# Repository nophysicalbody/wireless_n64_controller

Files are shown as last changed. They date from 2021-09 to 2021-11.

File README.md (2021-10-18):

# Wireless Nintendo 64 Controller Project

## Overview

This page describes my project to make a Nintendo 64 controller wireless. 
You plug your favourite controller into the transmitter, then plug the receiver into the console.
There is currently no support for controller peripherals (e.g.: memory cards, rumble packs).

The system is built on Arduino/AVR and utilises the popular RFM69 radio modules for wireless communication.

## Hardware

### Transmitter

The transmitter (what you plug the controller into) consists of:

* 3.3V Arduino Pro Mini, the brains of the operation
* Sparkfun RFM69 Breakout, to enable wireless communication
* Breadboard, breadboard power supply and a power source (for portability, I used a 7.4V battery)
* Half a N64 controller extension cord (the end that connects to a controller)
* A 1K ohm resistor to pull the N64 signal line high.

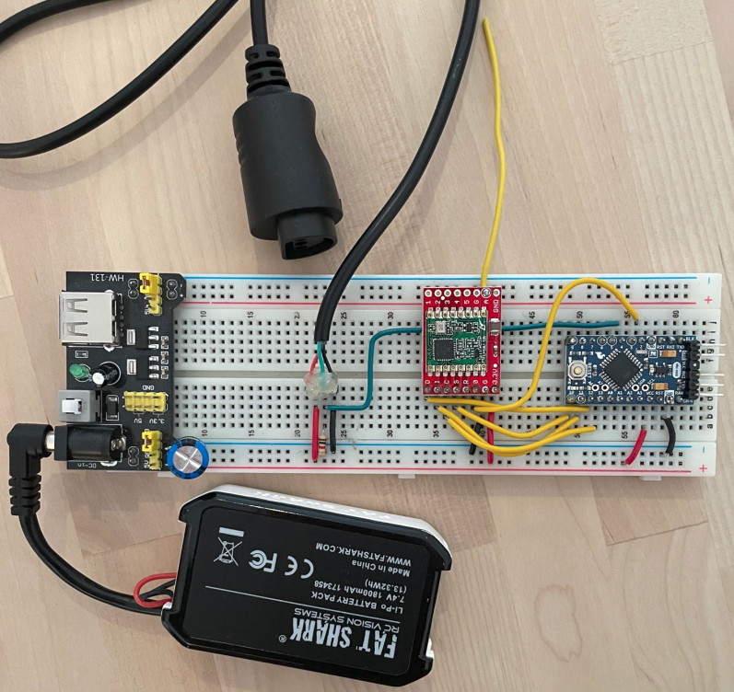
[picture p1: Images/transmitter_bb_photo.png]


### Receiver

The receiver (what you plug into the console) consists of:

* Another 3.3V Arduino Pro Mini
* Another Sparkfun RFM69 Breakout
* ATtiny85 dedicated to handling communication with the console
* Breadboard - no need for breadboard power supply as this board sources power from the console
* The other half of the N64 controller extension cord (the end that connects to the console)
* [Optional] - A bi-color LED indicator & resistor (this lights up when a button is pressed)

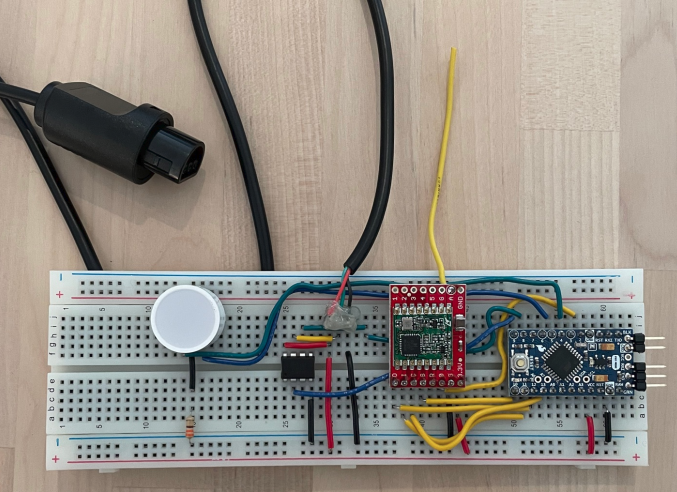
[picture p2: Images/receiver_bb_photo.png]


## Software

Transmitter software is located in the **wireless_n64_controller** sketch.
Flash **wireless_n64_controller.ino** to the Arduino Pro Mini on the transmitter.

Receiver software is located in the **wireless_n64_receiver** sketch.
Flash **wireless_n64_receiver.ino** to the Arduino Pro Mini on the receiver.
Flash **ATtiny85-n64-controller.ino** to the ATtiny85 on the receiver - refer to the "ATtiny85 programming instructions" document.

## Breadboard prototype set up

### Transmitter (Connect to controller)

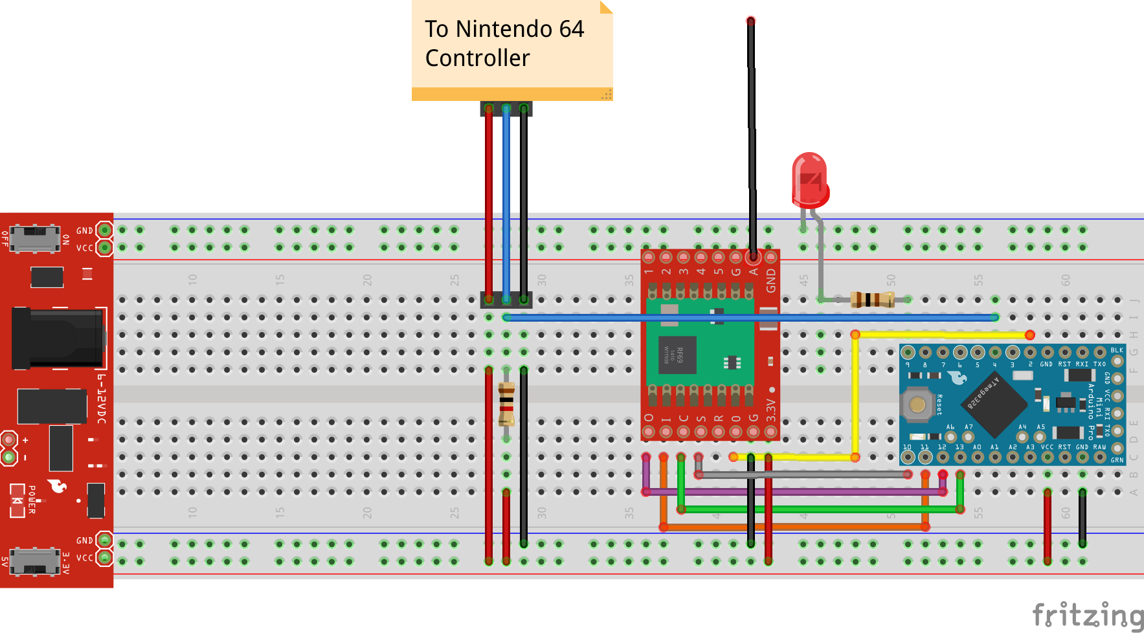
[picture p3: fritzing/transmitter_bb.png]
Transmitter


### Receiver (Connect to console)

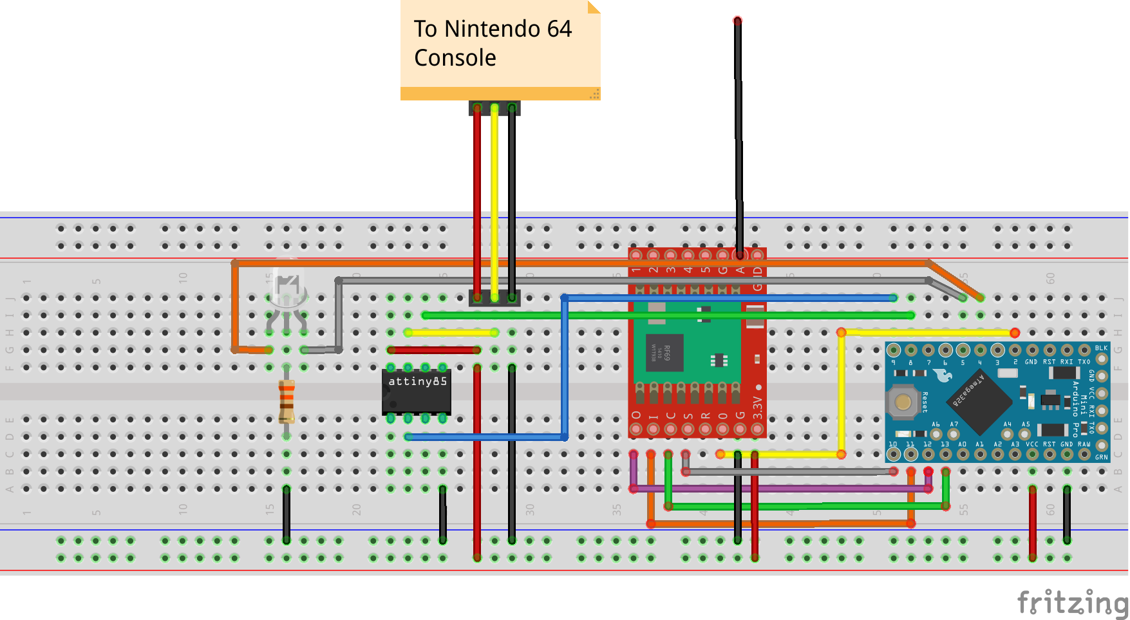
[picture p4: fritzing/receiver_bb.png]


#### ATtiny85 pinout:

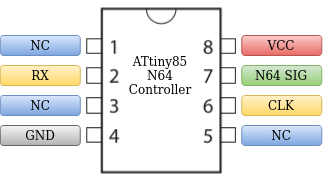
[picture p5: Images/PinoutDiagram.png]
Pinout


## Reference

The giants whose shoulders I stood on while building this:

http://www.pieter-jan.com/node/10

http://www.qwertymodo.com/hardware-projects/n64/n64-controller

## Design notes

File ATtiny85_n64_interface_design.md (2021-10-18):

# Nintendo 64 interface design

The idea is to have a device that acts as a virtual Nintendo 64 controller when connected to a Nintendo 64 console.
Instead of having physical buttons and a joystick, it has an SPI "inspired" interface which can be connected to an Arduino or any other microcontroller. 

## N64 console

<u>**Protocol: Proprietary Nintendo 64 serial protocol.**</u>

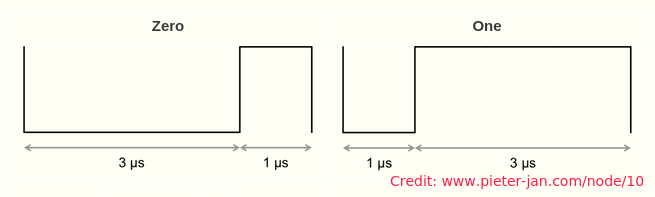
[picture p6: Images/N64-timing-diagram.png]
N64-timing-diagram


Goal: To respond to commands from the Nintendo 64 console
Building on the great reverse-engineering done by Pieter-Jan and qwerty-modo (links below) I developed a bit-bashing implementation of the protocol in assembly on the ATtiny85.

http://www.qwertymodo.com/hardware-projects/n64/n64-controller
http://www.pieter-jan.com/node/10

The Nintendo 64 console sends commands to the controller, which can be polls for controller state and controller configuration (currently supported) or to read/write the controller's memory pack (currently not supported). 

Button and joystick states are polled for, by the console. The console polls the controller at roughly 25 Hz during normal gameplay (At least, as measured by me while playing Diddy Kong Racing). The console also periodically requests a status update from the controller, which the controller uses to indicate things such as whether there is a rumble pack or memory pack inserted.

During console startup and transition points in the game's program, these requests seem to speed up/slow down, leading to brief periods of much higher/random frequencies.

The interface is handled via interrupts written in inline assembly. Getting C variables in and out of an assembly routine is cryptic at the best of times, so for anyone trying to build on what I created refer to this guide to make interpreting it easier:
https://www.nongnu.org/avr-libc/user-manual/inline_asm.html

## Arduino / other microcontroller

**<u>Protocol: SPI "inspired" protocol, specifically designed to accommodate clock-stretching.</u>**

Goal: To provide a simple and reliable way to interface with the AVR n64 controller to set button and joystick states.

Not claiming it's a good implementation, but it's mine!

### Note: Why I didn't use serial

Initially I started using standard TTL serial. This worked, but not reliably.

Commands from the console are handled with interrupts, which can take up to ~160us to run. If a console command happens to co-incide with an asynchronous serial TTL transmission (as used by the standard Arduino Serial or SoftwareSerial libraries), this delay de-synchronises the sender and receiver, leading to corruption of the incoming packets.

I initially tried to work around this using a CTS (clear to send) I/O line. By assuming the 25Hz update frequency, I could time pulses of CTS to occur immediately after the command was processed. The reliability improved a bit, but was still far from iron-clad as at times the commands from the console would come faster than expected (for instance, during console start up) and still lead to corruption.

To solve this problem I moved to a synchronous protocol like SPI, which has a dedicated clock line.
The clock line is controlled by the ATtiny chip, so if required it can hold the clock in the current state while it services the N64 console command routine without interrupting the transmission of virtual controller status change requests from the external device.

Below is a capture from my test-bench, which shows an interrupted transmission.

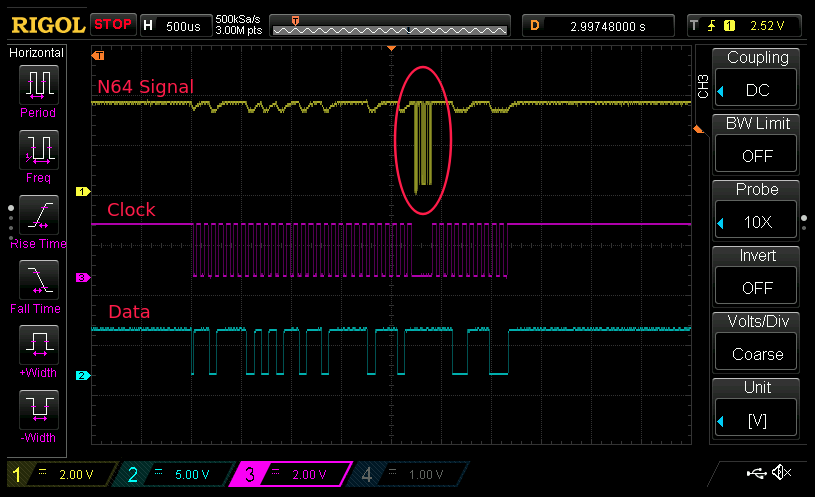
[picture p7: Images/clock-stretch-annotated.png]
clock-stretch-annotated


You can clearly see how the clock line pauses while the ATtiny chip services a poll request from the N64 console. This pause can be detected by the sender (which controls the Data line, shown in blue above) so the participants can remain in sync and the data is not corrupted.

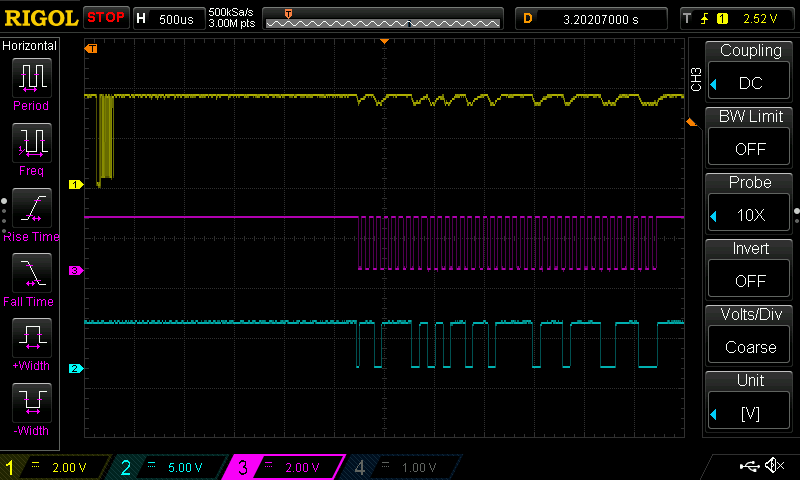
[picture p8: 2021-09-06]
Images/no-clock-stretch.png

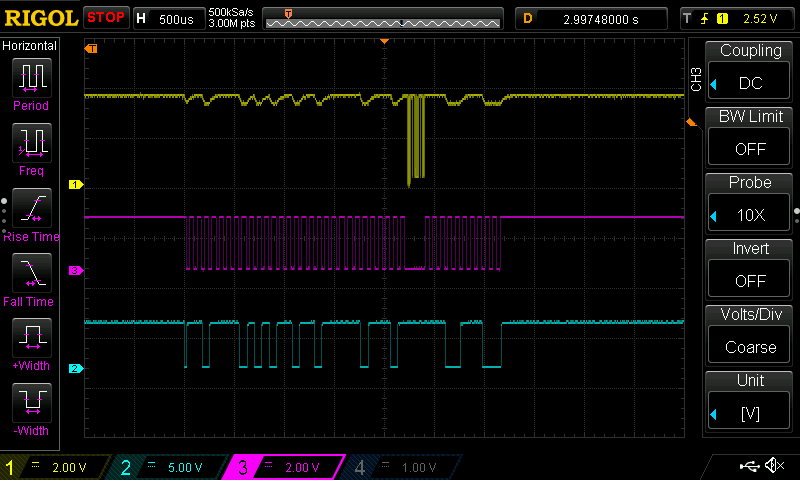
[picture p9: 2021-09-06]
Images/clock-stretch.png

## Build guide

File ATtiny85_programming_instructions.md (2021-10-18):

# ATtiny85 programming instructions

For this guide, I will be using the dedicated Tiny AVR Programmer, but you can use any supported method to flash the ATtiny85.

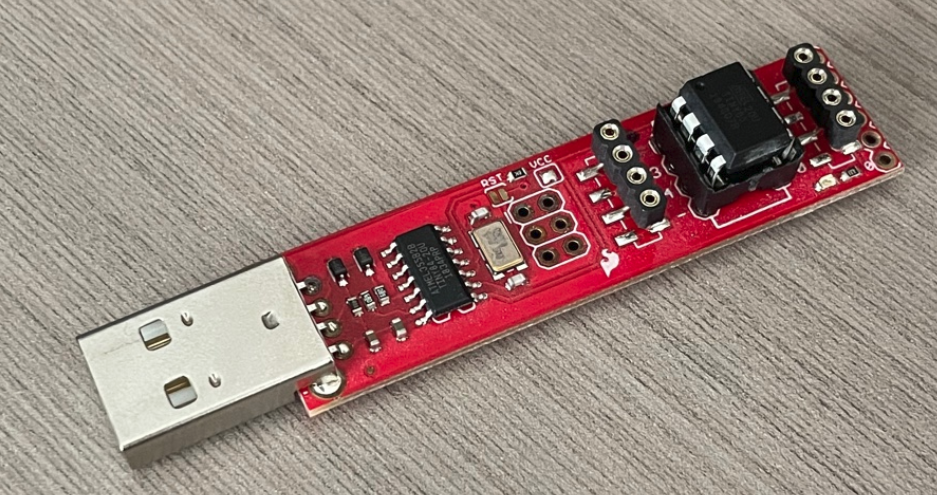
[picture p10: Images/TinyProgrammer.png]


## Step 0: setup

Before following the instructions for setting fuses or uploading the program below, you need to ensure you have the following set up:

* An AVR programmer installed and set up on your PC.
  * For the Tiny AVR programmer, the Sparkfun hookup guide covers all of this so I will not repeat the instructions here.
    https://learn.sparkfun.com/tutorials/tiny-avr-programmer-hookup-guide
  * If you are one of those cool folks using Ubuntu/Linux, the process is slightly different. Refer to the excellent guide here:
    https://www.sigmdel.ca/michel/program/avr/sparkfun_tiny_programmer_en.html
* The Arduino IDE installed on your PC
* The ATtiny board installed in your Arduino IDE.

## Step 1: set fuses

Hook up your ATtiny to your programmer, and connect the programmer to your PC.

From the command line run the following command. This will confirm whether the ATtiny and the programmer are hooked up correctly.

```
~$ avrdude -c usbtiny -p attiny85
avrdude: AVR device initialized and ready to accept instructions
Reading | ################################################## | 100% 0.01s
avrdude: Device signature = 0x1e930b (probably t85)
avrdude: safemode: Fuses OK (E:FF, H:DF, L:62)
avrdude done.  Thank you.
```

We need to set the fuses of the ATtiny85 so it operates using the internal oscillator and does not divide the system clock by 8 - meaning it runs at 8MHz instead of 1MHz. To do this, run the below command:

```
~$ avrdude -c usbtiny -p attiny85 -U lfuse:w:0xE2:m -U hfuse:w:0xDF:m -U efuse:w:0xFF:m
avrdude: AVR device initialized and ready to accept instructions
...
... many lines later ...
...
avrdude: safemode: Fuses OK (E:FF, H:DF, L:E2)
avrdude done.  Thank you.
```

## Step 2: upload program

To compile and upload the firmware, use the Arduino IDE.

Open the `ATtiny85-n64-controller.ino` file in the Arduino IDE.

Select the board type as `ATtiny25/45/85` under `Tools -> Board -> ATtiny Microcontrollers.`

Select the processor as `ATtiny85` under `Tools -> Processor`.

Select the clock as `Internal 8MHz` under `Tools -> Clock`.

Select the programmer as `USBtinyISP` under `Tools -> Programmer`

With this done, compile and upload the program by pressing the upload button `(Ctrl+U)`

## Step 3: celebrate your victory

The ATtiny85 is now flashed and ready to be included in your circuit!

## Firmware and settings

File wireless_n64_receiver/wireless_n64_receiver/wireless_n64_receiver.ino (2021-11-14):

#define A_IDX       0x80000000
#define B_IDX       0x40000000
#define Z_IDX       0x20000000
#define START_IDX   0x10000000
#define D_UP_IDX    0x08000000
#define D_DOWN_IDX  0x04000000
#define D_LEFT_IDX  0x02000000
#define D_RIGHT_IDX 0x01000000
#define L_IDX       0x00200000
#define R_IDX       0x00100000
#define C_UP_IDX    0x00080000
#define C_DOWN_IDX  0x00040000
#define C_LEFT_IDX  0x00020000
#define C_RIGHT_IDX 0x00010000
#define X_IDX       0x0000FF00
#define Y_IDX       0x000000FF

// Include the RFM69 and SPI libraries:
#include <RFM69.h>
#include <SPI.h>

// Addresses for this node. CHANGE THESE FOR EACH NODE!
#define NETWORKID     0   // Must be the same for all nodes
#define MYNODEID      2   // My node ID
#define TONODEID      1   // Destination node ID

// RFM69 frequency, uncomment the frequency of your module:
#define FREQUENCY     RF69_915MHZ

// AES encryption (or not):
#define ENCRYPT       true // Set to "true" to use encryption
#define ENCRYPTKEY    "TOPSECRETPASSWRD" // Use the same 16-byte key on all nodes

#define GN_LED 5
#define RD_LED 4
#define TX_PIN 9    // Connect to ATtiny85 N64 Controller RX pin
#define CLK_PIN 8   // Connect to ATtiny85 N64 Controller CLK pin
#define TIMEOUT_PERIOD_MS 2

// Create a library object for our RFM69HCW module:
RFM69 radio;

int synchronous_write_byte(byte out){
  for (int b=0; b<8; b++) {
    // Wait for falling edge on CLK_PIN
    long start_time = millis();
    while (digitalRead(CLK_PIN)) {
      if ((millis() - start_time) > TIMEOUT_PERIOD_MS) {
        return 0; // Indicate timeout
      }
    }
    // Rising edge has occurred. Write MSB to TX_PIN
    digitalWrite(TX_PIN, out & 0b10000000);
    out = out << 1;

    // Wait for rising edge:
      while (!digitalRead(CLK_PIN)) {
      if ((millis() - start_time) > TIMEOUT_PERIOD_MS) {
        return 0; // Indicate timeout
      }
    }
  }
  return 1;
}

void write_32_bit_controller_value(uint32_t out){
  // Assemble components
  byte byte_0 = (out >> 24) & 0xFF;
  byte byte_1 = (out >> 16) & 0xFF;
  byte byte_2 = (out >> 8) & 0xFF;
  byte byte_3 = out & 0xFF;
  byte checksum = byte_0 + byte_1 + byte_2 + byte_3;

  // Send bytes to virtual controller
  digitalWrite(TX_PIN, LOW); // Set TX line low to indicate we wish to start sending
  synchronous_write_byte(byte_0);
  synchronous_write_byte(byte_1);
  synchronous_write_byte(byte_2);
  synchronous_write_byte(byte_3);
  synchronous_write_byte(checksum);
  digitalWrite(TX_PIN, HIGH);
}

void setup()
{
  // Open a serial port so we can send keystrokes to the module:

  Serial.begin(9600);
  Serial.print("Node ");
  Serial.print(MYNODEID,DEC);
  Serial.println(" ready");  

  // Initialize the RFM69HCW:
  radio.initialize(FREQUENCY, MYNODEID, NETWORKID);
  radio.setHighPower(); // Always use this for RFM69HCW
  // Turn on encryption if desired:
  if (ENCRYPT)
    radio.encrypt(ENCRYPTKEY);

  // set up indicators
  pinMode(GN_LED, OUTPUT);
  pinMode(RD_LED, OUTPUT);
  // set up IO for virtual n64 controller interface
  pinMode(CLK_PIN, INPUT);
  pinMode(TX_PIN, OUTPUT);
}


unsigned long n64_status;

void loop()
{
  if (radio.receiveDone() && (radio.DATALEN==4)) // Got a 4 byte n64 status
  {
    n64_status = 0;
    // Read out the information:
    for (byte i = 0; i < 4; i++){
      n64_status = n64_status << 8;
      n64_status += radio.DATA[i];
    }

    // If the A button is pressed, light the green indicator
    digitalWrite(GN_LED, bool(n64_status & A_IDX));
    // If the Start button is pressed, light the red indicator
    digitalWrite(RD_LED, bool(n64_status & START_IDX));

    // Pass the update synchronously to the virtual n64 controller
    write_32_bit_controller_value(n64_status);
    //Serial.println(n64_status, HEX);
  }
}

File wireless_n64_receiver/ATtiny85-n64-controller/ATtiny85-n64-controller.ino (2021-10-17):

#include "src/n64_console_if.h"

// I/O connections
const int N64_SIG_PIN = 2;
const int CLK_PIN = 1;
const int RX_PIN = 3;

// Syncronous SPI "inspired" communications
const int serial_half_period_delay_us = 26; /* (1000000 / (BAUDRATE * 2)) = 26, if BAUDRATE is 19200 */

// Buffers to hold controller configuration, button/joystick state, and commands read from the console
volatile byte N64_CONTROLLER_STATE[4] = {0,0,0,0};          // Button/joystick state
volatile byte N64_CONTROLLER_STATUS[3] = {0x05,0x00,0x00};  // Controller configuration
volatile byte console_command;                              // Commands from the console

// The interrupt service routine - this is where the magic happens!
ISR(INT0_vect)
{
  // Runs when falling edge detected on N64 signal pin. I.e: Console is sending command!
  
  // Firstly, turn off all other interrupts (this section is carefully timed assembly)
  GIMSK = 0; 

  // Read the command from the console, store in console_command
  console_command = n64_read();

  // Reply to console command with the requested information
  if (console_command == N64_REQUEST_STATUS) {
    n64_send(N64_CONTROLLER_STATUS, 3);
  } else if (console_command == N64_REQUEST_POLL) {
    n64_send(N64_CONTROLLER_STATE, 4);
  }
  
  // Clear INTF0, otherwise ISR will run again!
  GIFR = (1<<INTF0);
  GIMSK = 0b01100000; // turn interrupts back on
}

// Serial for troubleshooting
//#include <SoftwareSerial.h>
//SoftwareSerial Ser(0,4); // RX, TX

void setup()
{
  // Set up DDRs
  pinMode(N64_SIG_PIN, INPUT);
  pinMode(RX_PIN, INPUT);
  pinMode(CLK_PIN, OUTPUT);

  // Set outputs to the correct initial state
  digitalWrite(CLK_PIN, HIGH);

  // Set WatchDog Timer Control Register (0x21) to 0x0E to enable a 1 second watchdog timer that resets.
  asm volatile(
    "push r16     \n\t"
    "ldi r16, 0x0E \n\t"
    "out 0x21, r16 \n\t"
    "pop r16      \n\t"
  );
  
  // Configure pin change interrupts on pin 2.
  GIMSK |= (1 << INT0);   // external interrupt enable
  MCUCR = 0b10;           // configure to trigger interrupt on falling edge
  sei();                  // enable interrupts
  
  // Serial for troubleshooting
  //Ser.begin(19200);
}

byte synchronous_read_byte() {
  byte buff = 0x00;
  for (int b=0; b<8; b++){
      /* CLK LOW - signal change to transmitter */
      digitalWrite(CLK_PIN, LOW);
      delayMicroseconds(serial_half_period_delay_us);
      buff = buff << 1;
      
      /* CLK HIGH - read bit */
      digitalWrite(CLK_PIN, HIGH);
      buff |= digitalRead(RX_PIN);
      delayMicroseconds(serial_half_period_delay_us);
    }
  return buff;
}

// Variables for reading button/joystick state from controller
byte incomingByte0;
byte incomingByte1;
byte incomingByte2;
byte incomingByte3;
byte checksumByte;

bool previous_rx_state = HIGH;
bool update_available = false;

void loop()
{
  // Reset Watchdog
  asm volatile("wdr \n\t");
  
  // Handle external commands:
  bool rx_state = digitalRead(RX_PIN);
  
  if (previous_rx_state && !rx_state) 
  {
    // We have detected a falling edge on the RX line, this indicates a transmit request.
    
    // Read into buffers:
    incomingByte0 = synchronous_read_byte();
    incomingByte1 = synchronous_read_byte();
    incomingByte2 = synchronous_read_byte();
    incomingByte3 = synchronous_read_byte();
    checksumByte  = synchronous_read_byte();

    // Calculate checksum and set flag if we're ready to update:
    if (((incomingByte0 + incomingByte1 + incomingByte2 + incomingByte3) & 0xFF) == checksumByte) {
      update_available = true;
    } else {
      update_available = false;
    }
  }

  if (update_available) {
    // Turn off external interrupts (but allow pin change interrupts) - make changes to ISR variables here!
    GIMSK = 0b00100000; 
    N64_CONTROLLER_STATE[0] = incomingByte0;
    N64_CONTROLLER_STATE[1] = incomingByte1;
    N64_CONTROLLER_STATE[2] = incomingByte2;
    N64_CONTROLLER_STATE[3] = incomingByte3;
    GIMSK = 0b01100000; // turn external interrupts back on
    update_available = false;
  }
  
  previous_rx_state = rx_state;
}

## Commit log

2021-08-08 Added assembly code to interface with N64 controller
2021-08-09 Fixed transmission of n64 data
    [wireless_n64_controller.ino, wireless_n64_receiver.ino]
2021-08-14 Added more efficient send logic + LEd indicator on reciever
2021-10-17 Added fritzing breadboard diagrams
    [receiver.fzz, transmitter.fzz]
2021-10-23 Added controller activity LED to breadboard diagrams
    [transmitter.fzz]
2021-11-14 fixed controller button flags
    [wireless_n64_receiver.ino]
